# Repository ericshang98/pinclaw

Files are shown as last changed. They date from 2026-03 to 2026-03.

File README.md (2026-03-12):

<div align="center">

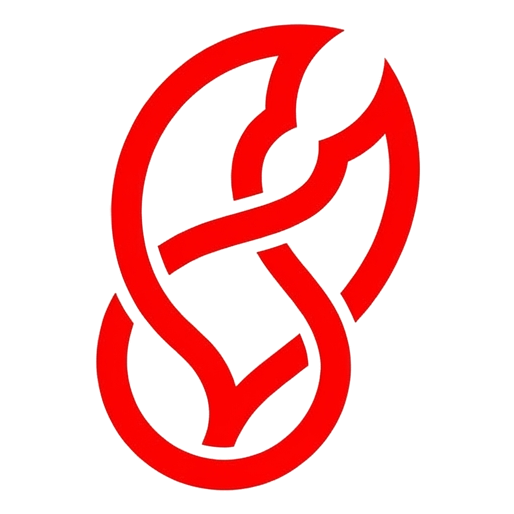
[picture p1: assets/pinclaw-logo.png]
Pinclaw

PinClaw

<a href="https://pinclaw.ai">pinclaw.ai</a>

The first hardware product built for [OpenClaw](https://openclaw.ai). A tiny wearable AI clip — always listening, always acting, powered by your own AI agent.

<p align="center">
  Pinclaw
</p>

&ensp;&ensp;&ensp;
&ensp;&ensp;&ensp;
&ensp;&ensp;&ensp;


<h3>

[Website](https://pinclaw.ai) | [App Store](https://apps.apple.com/app/pinclaw/id6760344343) | [Docs](https://pinclaw.ai/doc) | [Buy Pinclaw](https://pinclaw.ai/#pricing)

</h3>

</div>

## Your Closest Agent. &ensp; OpenClaw + Pinclaw

We believe AI agents should feel effortless — not something you open, but something that's just there. Pinclaw is designed to let agents truly integrate into your life. No screen to unlock, no app to open. Just speak, and your agent hears you, thinks, and acts.

Your own server, your own AI agent, ready to go. Powered by [OpenClaw](https://openclaw.ai).

## 🎙 Why Us

- **5× faster input** — Phone: unlock, open app, type (~30s). Pinclaw: tap, speak, done (~6s). Language is the most natural interface.
- **Your phone, unlocked** — Pinclaw talks directly to your iPhone. Calendar, reminders, contacts — your AI agent uses them without you ever touching the screen.
- **No screen required** — Clip it on and forget it. Ask questions, set reminders, get updates — all hands-free, all voice.

## 🛠 Quick Start

```bash
openclaw plugin add @openclaw/pinclaw
openclaw gateway --force
```

[](https://apps.apple.com/app/pinclaw/id6760344343)

→ [Full setup guide](https://pinclaw.ai/doc?tab=getting-started)

For a complete setup guide, see the [documentation](https://pinclaw.ai/doc).

## ☁️ Works With Every Claw

Pinclaw integrates with the entire OpenClaw ecosystem — cloud or self-hosted, plug in and go.

| Platform | Type | Platform | Type |
|---|---|---|---|
| [**OpenClaw**](https://openclaw.ai) | Self-hosted | **ClawApp** | Managed |
| **KiloClaw** | Managed | **EasyClaw** | Managed |
| **Clawi.ai** | Managed | **HostedClaws** | Managed |
| **chowder.dev** | Managed | **ClawSimple** | Managed |

One plugin. Any platform. Your choice.

## 📲 Device Skills

Other AI hardware lives in a bubble — it can't see your calendar, doesn't know your contacts, and has no idea what you did today. Pinclaw is different.

<p align="center">
  Pinclaw Device Skills
</p>

| Skill | What Your Agent Can Do |
|---|---|
| **Calendar** | View and create events, check availability |
| **Reminders** | Manage tasks and to-do lists |
| **Contacts** | Search your contacts |
| **Timer** | Set and cancel timers |
| **Health** | Read health data summaries |
| **Location** | Get your current location |
| **HomeKit** | Control your smart home devices |

> All data stays on your iPhone. You control every permission.

## 🔀 Two Ways to Use

**Cloud Mode — Zero Setup**
Buy the clip, download the app, subscribe. We run a dedicated OpenClaw instance for you — your own agent, your own database, managed by us.

**My OpenClaw Mode — Full Control**
Run OpenClaw on your own machine. Install the plugin, connect via relay. Your AI, your rules, your hardware.

## 🔩 Core Technologies

| Technology | Description |
|---|---|
| **BLE Audio Streaming** | High-quality audio streams wirelessly over BLE. Custom packet protocol with CRC32 integrity checks. |
| **On-Device Speech Recognition** | Transcribed locally on iPhone using Apple Speech. No audio leaves your device. |
| **AI Agent Services** | Connect to Claude, GPT, and other frontier models through the OpenClaw platform. |

## 📂 In this repo:

- [plugin](plugin) — OpenClaw channel plugin (`@openclaw/pinclaw`), TypeScript
- [firmware](firmware) — Zephyr RTOS firmware for XIAO nRF52840 Sense, C
- [hardware](hardware) — 3D case designs (Fusion 360 / STL), PCB files

## 📖 Documentation:

- [Introduction](https://pinclaw.ai/doc)
- [Getting Started](https://pinclaw.ai/doc?tab=getting-started)
- [Core Protocol](https://pinclaw.ai/doc?tab=core)
- [Plugin Development](https://pinclaw.ai/doc?tab=plugin)
- [API Reference](https://pinclaw.ai/doc?tab=reference)

## 🤝 Contributions

- Check out the [current issues](https://github.com/ericshang98/pinclaw/issues).
- Join the [Discord](https://discord.gg/628R3FbV).
- Fork, branch, and open a Pull Request.

## 📄 Licensing

Pinclaw is available under <a href="https://github.com/ericshang98/pinclaw/blob/main/LICENSE">MIT License</a>

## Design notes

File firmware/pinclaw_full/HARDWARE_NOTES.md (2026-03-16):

# Pinclaw PCB V1.0 Hardware Notes

## Button Pin Mapping (IMPORTANT — pins are swapped vs silkscreen!)

The physical buttons on the PCB are **swapped** relative to the schematic labels:

| Physical Button | Actual GPIO | Firmware Function |
|---|---|---|
| Left button (closer to USB) | D5 | PTT (Push-to-Talk, recording) |
| Right button (further from USB) | D4 | Action (Play / SD sync) |

**The schematic says D4=PTT, D5=Action, but the actual wiring is reversed.**

This means in firmware:
- `PIN_PTT` should be `5` (not `4`)
- `PIN_ACTION` should be `4` (not `5`)

## Known Issues

- Both recording (PDM mic) and playback (I2S speaker) exhibit audible electrical noise / buzzing
- Possible causes: PDM clock interference, shared power rail noise, missing decoupling caps

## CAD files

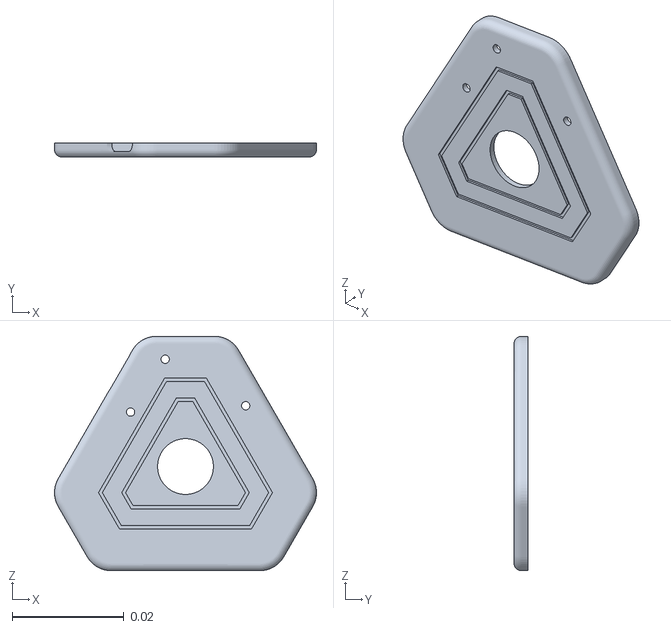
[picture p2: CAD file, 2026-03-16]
hardware/enclosure/stl/speaker_grille.stl
0.0469 x 0.0025 x 0.042

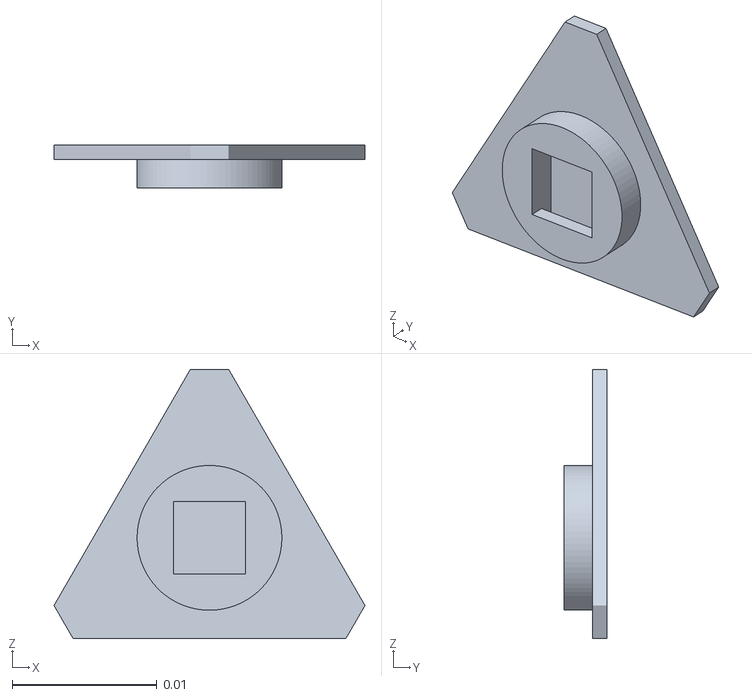
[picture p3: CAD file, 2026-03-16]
hardware/enclosure/stl/button_cap.stl
0.0215 x 0.003 x 0.0186

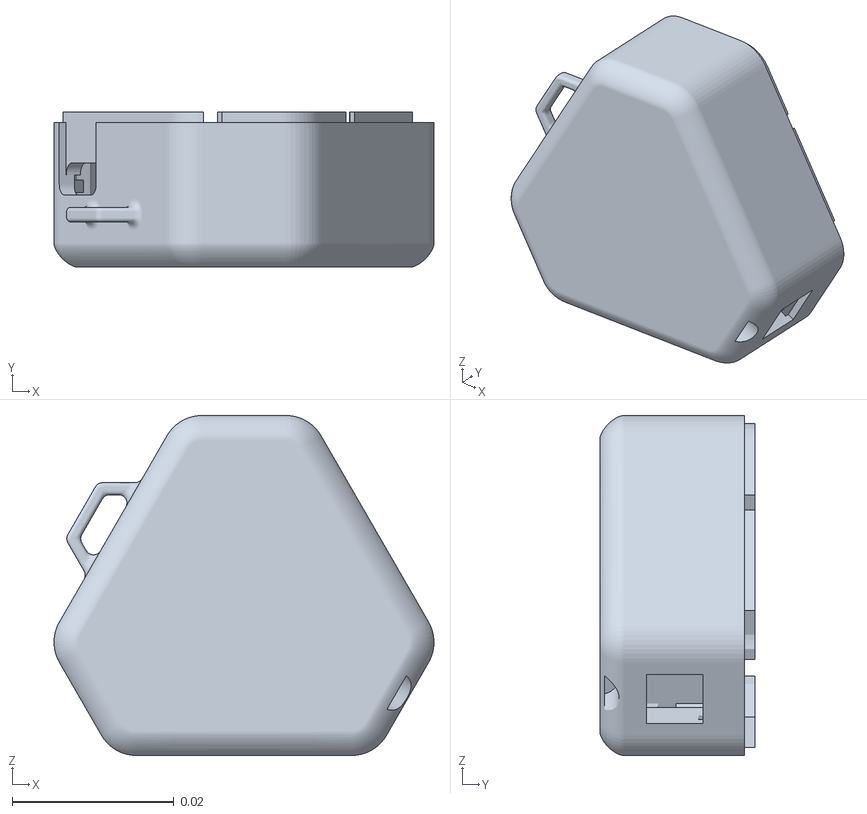
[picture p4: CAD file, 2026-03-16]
hardware/enclosure/stl/base.stl
0.0469 x 0.0192 x 0.042

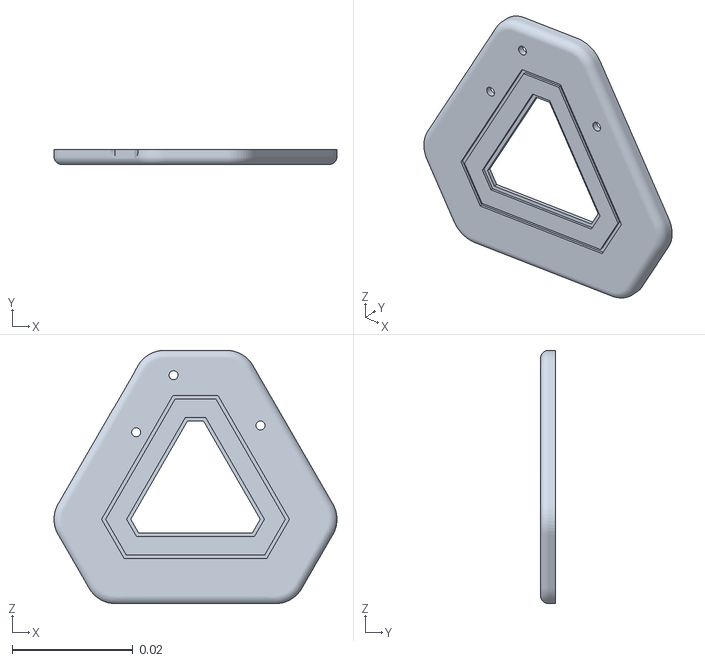
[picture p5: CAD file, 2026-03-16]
hardware/enclosure/stl/top_cover.stl
0.0469 x 0.0025 x 0.042

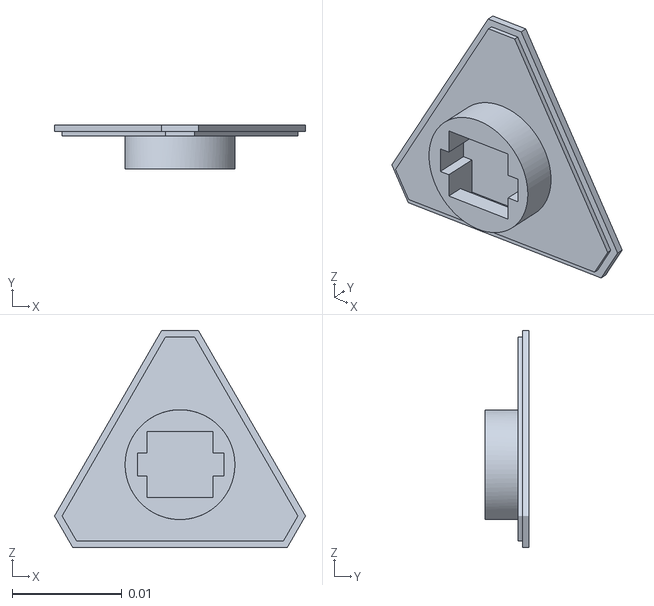
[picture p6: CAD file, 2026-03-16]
hardware/enclosure/stl/button_key.stl
0.0229 x 0.004 x 0.0198

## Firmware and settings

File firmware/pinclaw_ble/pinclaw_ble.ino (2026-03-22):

// Pinclaw BLE Audio Clip — XIAO nRF52840 Sense Firmware
// Records PDM microphone audio, encodes with Opus (CELT mode), streams via BLE in real-time
// iPhone triggers recording via BLE write command (0x01=start, 0x00=stop)

#include <bluefruit.h>
#include <PDM.h>

extern "C" {
  #include "opus.h"
}

// ============================================================
// BLE UUIDs — must match iOS app and Mac simulator
// ============================================================
#define SERVICE_UUID       "12345678-1234-1234-1234-123456789ABC"
#define TEXT_CHAR_UUID     "12345678-1234-1234-1234-123456789ABD"
#define AUDIO_CHAR_UUID    "12345678-1234-1234-1234-123456789ABE"
#define HEARTBEAT_CHAR_UUID "12345678-1234-1234-1234-123456789ABF"

// ============================================================
// BLE packet types
// ============================================================
#define PKT_START     0x01
#define PKT_DATA      0x02
#define PKT_END       0x03
#define PKT_HEARTBEAT 0x04

// ============================================================
// Single-button config
// ============================================================
#define PIN_BUTTON        5   // D5 — single button (active LOW, internal pullup)
#define DEBOUNCE_MS       50
#define LONG_PRESS_MS     500  // hold > 500ms = start recording
#define DOUBLE_TAP_MS     300  // window for second tap
#define CMD_PLAY          0x20 // button tap → phone triggers Interactive AI

// ============================================================
// Audio config
// ============================================================
#define SAMPLE_RATE       16000
#define PDM_BUFFER_SIZE   512    // samples per PDM callback
#define MAX_RECORD_SEC    10
#define SILENCE_THRESHOLD 600   // tuned for 0dB PDM gain (noise peak ~400)
#define SILENCE_TIMEOUT_MS 5000

// BLE MTU and packet sizing
// nRF52840 max MTU = 247, ATT header = 3, so max notify payload = 244
#define BLE_MTU           247
#define DATA_HEADER_SIZE  3     // type(1) + seqNo(2)
#define DATA_PAYLOAD_SIZE (BLE_MTU - DATA_HEADER_SIZE)  // 244

// ============================================================
// Opus encoder config
// ============================================================
#define OPUS_FRAME_SAMPLES 160   // 10ms at 16kHz
#define OPUS_MAX_PACKET    320   // max encoded frame bytes
#define OPUS_ENCODER_SIZE  7180  // opus_encoder_get_size(1)

// Codec ID for BLE START packet (matches OMI/Friend project)
#define CODEC_OPUS 0x14

// ============================================================
// State machine
// ============================================================
enum FirmwareState {
  STATE_INIT,
  STATE_IDLE,
  STATE_RECORDING
};

volatile FirmwareState currentState = STATE_INIT;

// ============================================================
// BLE objects
// ============================================================
BLEService        pinclawService(SERVICE_UUID);
BLECharacteristic textChar(TEXT_CHAR_UUID);
BLECharacteristic audioChar(AUDIO_CHAR_UUID);
BLECharacteristic heartbeatChar(HEARTBEAT_CHAR_UUID);

// ============================================================
// PDM microphone
// ============================================================
short pdmBuffer[PDM_BUFFER_SIZE];
volatile int pdmSamplesRead = 0;

// ============================================================
// Opus encoder state (statically allocated, no malloc)
// ============================================================
static uint8_t opusState[OPUS_ENCODER_SIZE] __attribute__((aligned(4)));
static OpusEncoder* opusEnc = (OpusEncoder*)opusState;

// PCM accumulator for Opus frames (160 samples = 10ms)
int16_t pcmAccum[OPUS_FRAME_SAMPLES];
int pcmAccumPos = 0;
uint16_t opusSeqNo = 0;
uint8_t opusOutBuf[OPUS_MAX_PACKET];

// Silence detection
volatile uint32_t lastSoundTime = 0;
volatile uint32_t recordStartTime = 0;

// Heartbeat
uint16_t heartbeatCounter = 0;
uint32_t lastHeartbeatTime = 0;
#define HEARTBEAT_INTERVAL_MS 50000  // 50 seconds

// Connection state
volatile bool isConnected = false;

// Serial test mode (record via serial command, dump Opus frames to serial)
volatile bool serialTestMode = false;

// ============================================================
// Single-button state
// ============================================================
bool btnPressed = false;
bool lastBtnState = HIGH;
uint32_t lastBtnDebounce = 0;
uint32_t btnPressTime = 0;
uint32_t btnReleaseTime = 0;
uint8_t tapCount = 0;
bool btnRecording = false;  // true while long-press recording is active

// === 2nd-order Butterworth high-pass filter at 80Hz ===
// Removes 50Hz mains hum + DC offset while preserving speech (fundamental ~100Hz+)
// Designed for fs=16000Hz, fc=80Hz
// Pre-computed coefficients (scipy.signal.butter(2, 80/8000, 'high'))
#define HPF2_B0  0.96907f
#define HPF2_B1 -1.93815f
#define HPF2_B2  0.96907f
#define HPF2_A1 -1.93729f
#define HPF2_A2  0.93900f
float hpfX1 = 0, hpfX2 = 0;  // input delay line
float hpfY1 = 0, hpfY2 = 0;  // output delay line

// === Noise gate (two-stage) ===
// Stage 1: Per-sample soft gate — anything below SOFT_GATE is zeroed
// Stage 2: Per-chunk hard gate — if chunk RMS < HARD_GATE, zero the whole chunk
// This ensures silence is truly silent while preserving speech dynamics
#define SOFT_GATE_THRESHOLD  120   // per-sample: below this amplitude -> 0
#define HARD_GATE_THRESHOLD_SQ (400L * 400L)  // per-chunk RMS^2: below this -> all zeros

// Startup discard — skip first N ms of PDM data (transient)
#define STARTUP_DISCARD_MS 80
volatile bool startupDiscardDone = false;


// ============================================================
// Base64 encoder (for serial test mode)
// ============================================================
static const char b64chars[] = "ABCDEFGHIJKLMNOPQRSTUVWXYZabcdefghijklmnopqrstuvwxyz0123456789+/";

void serialBase64(const uint8_t* data, uint32_t len) {
  char line[77];  // 76 chars + null
  int linePos = 0;

  for (uint32_t i = 0; i < len; i += 3) {
    uint32_t n = ((uint32_t)data[i]) << 16;
    if (i + 1 < len) n |= ((uint32_t)data[i + 1]) << 8;
    if (i + 2 < len) n |= data[i + 2];

    line[linePos++] = b64chars[(n >> 18) & 63];
    line[linePos++] = b64chars[(n >> 12) & 63];
    line[linePos++] = (i + 1 < len) ? b64chars[(n >> 6) & 63] : '=';
    line[linePos++] = (i + 2 < len) ? b64chars[n & 63] : '=';

    if (linePos >= 76) {
      line[linePos] = '\0';
      Serial.println(line);
      linePos = 0;
    }
  }
  if (linePos > 0) {
    line[linePos] = '\0';
    Serial.println(line);
  }
}


// ============================================================
// PDM callback — called from interrupt context
// ============================================================
void onPDMdata() {
  int bytesAvailable = PDM.available();
  PDM.read(pdmBuffer, bytesAvailable);
  pdmSamplesRead = bytesAvailable / 2;
}


// ============================================================
// Initialize Opus encoder
// ============================================================
void initOpusEncoder() {
  int err = opus_encoder_init(opusEnc, 16000, 1, OPUS_APPLICATION_RESTRICTED_LOWDELAY);
  if (err != OPUS_OK) {
    Serial.printf("[OPUS] encoder_init failed: %d\n", err);
    return;
  }

  opus_encoder_ctl(opusEnc, OPUS_SET_BITRATE(32000));
  opus_encoder_ctl(opusEnc, OPUS_SET_VBR(1));
  opus_encoder_ctl(opusEnc, OPUS_SET_VBR_CONSTRAINT(0));
  opus_encoder_ctl(opusEnc, OPUS_SET_COMPLEXITY(3));
  opus_encoder_ctl(opusEnc, OPUS_SET_SIGNAL(OPUS_SIGNAL_VOICE));
  opus_encoder_ctl(opusEnc, OPUS_SET_LSB_DEPTH(16));
  opus_encoder_ctl(opusEnc, OPUS_SET_DTX(0));
  opus_encoder_ctl(opusEnc, OPUS_SET_INBAND_FEC(0));
  opus_encoder_ctl(opusEnc, OPUS_SET_PACKET_LOSS_PERC(0));

  Serial.println("[OPUS] Encoder initialized (32kbps VBR, complexity=3, CELT lowdelay)");
}


// ============================================================
// Send one Opus frame via BLE as a DATA packet
// ============================================================
void sendOpusFrame(const uint8_t* frameData, int frameLen) {
  if (!isConnected || !audioChar.notifyEnabled()) return;

  // [0x02][seqNo 2B BE][opus_frame_data...]
  uint8_t pkt[DATA_HEADER_SIZE + OPUS_MAX_PACKET];
  pkt[0] = PKT_DATA;
  pkt[1] = (opusSeqNo >> 8) & 0xFF;
  pkt[2] = opusSeqNo & 0xFF;
  memcpy(&pkt[DATA_HEADER_SIZE], frameData, frameLen);

  sendWithRetry(pkt, DATA_HEADER_SIZE + frameLen);
  opusSeqNo++;
}


// ============================================================
// Encode accumulated PCM and send via BLE (or dump to serial)
// ============================================================
void encodeAndSendFrame() {
  int encodedLen = opus_encode(opusEnc, pcmAccum, OPUS_FRAME_SAMPLES, opusOutBuf, OPUS_MAX_PACKET);

  if (encodedLen < 0) {
    Serial.printf("[OPUS] encode error: %d\n", encodedLen);
    return;
  }

  if (serialTestMode) {
    // Dump Opus frame to serial for test script
    Serial.printf(">>> OPUS_FRAME %d\n", encodedLen);
    serialBase64(opusOutBuf, encodedLen);
  } else {
    sendOpusFrame(opusOutBuf, encodedLen);
  }
}


// ============================================================
// Process PDM samples: filter + encode + stream
// ============================================================
void processPDMSamples() {
  if (pdmSamplesRead == 0 || currentState != STATE_RECORDING) return;

  int count = pdmSamplesRead;
  pdmSamplesRead = 0;

  // Discard startup transient
  if (!startupDiscardDone) {
    if (millis() - recordStartTime < STARTUP_DISCARD_MS) {
      return;
    }
    startupDiscardDone = true;
  }

  int16_t peakAmplitude = 0;

  // --- Pass 1: HPF + per-sample soft gate ---
  int64_t energySum = 0;
  for (int i = 0; i < count; i++) {
    float x = (float)pdmBuffer[i];

    // 2nd-order Butterworth HPF at 80Hz — kills 50Hz hum + DC
    float y = HPF2_B0 * x + HPF2_B1 * hpfX1 + HPF2_B2 * hpfX2
                           - HPF2_A1 * hpfY1 - HPF2_A2 * hpfY2;
    hpfX2 = hpfX1; hpfX1 = x;
    hpfY2 = hpfY1; hpfY1 = y;

    int16_t sample = (int16_t)constrain((int32_t)y, -32768, 32767);

    // Per-sample soft gate: small amplitudes -> zero
    if (abs(sample) < SOFT_GATE_THRESHOLD) {
      sample = 0;
    }

    pdmBuffer[i] = sample;
    energySum += (int32_t)sample * sample;
  }

  // --- Per-chunk hard gate: if overall energy is low, zero everything ---
  int64_t avgEnergySq = energySum / count;
  bool gated = (avgEnergySq < HARD_GATE_THRESHOLD_SQ);

  // --- Pass 2: Accumulate into Opus frames and encode ---
  for (int i = 0; i < count; i++) {
    int16_t sample = gated ? 0 : pdmBuffer[i];

    int16_t absSample = abs(sample);
    if (absSample > peakAmplitude) peakAmplitude = absSample;

    // Feed into PCM accumulator
    pcmAccum[pcmAccumPos++] = sample;

    // When we have a full Opus frame (160 samples = 10ms), encode and send
    if (pcmAccumPos >= OPUS_FRAME_SAMPLES) {
      encodeAndSendFrame();
      pcmAccumPos = 0;
    }
  }

  // Update silence detection
  if (peakAmplitude > SILENCE_THRESHOLD) {
    lastSoundTime = millis();
  }

  uint32_t now = millis();

  // Auto-stop on silence (5 seconds)
  if (now - lastSoundTime > SILENCE_TIMEOUT_MS) {
    Serial.println("[REC] Auto-stop: silence detected");
    stopRecording();
    return;
  }

  // In serial test mode, use fixed 5-second duration
  if (serialTestMode && (now - recordStartTime > 5000UL)) {
    Serial.println("[TEST] 5s test recording complete");
    stopRecording();
    return;
  }

  // Hard stop at max duration
  if (now - recordStartTime > (MAX_RECORD_SEC * 1000UL)) {
    Serial.println("[REC] Auto-stop: max duration reached");
    stopRecording();
    return;
  }
}


// ============================================================
// Recording control
// ============================================================
void startRecording() {
  if (currentState != STATE_IDLE) return;

  Serial.println("[REC] Starting recording...");

  // Reset Opus encoder state
  opus_encoder_ctl(opusEnc, OPUS_RESET_STATE);

  // Reset PCM accumulator and sequence number
  pcmAccumPos = 0;
  opusSeqNo = 0;

  // Reset filter state
  hpfX1 = hpfX2 = hpfY1 = hpfY2 = 0;
  startupDiscardDone = false;

  // Reset silence detection
  lastSoundTime = millis();
  recordStartTime = millis();

  // Send START packet immediately: [0x01][codec=0x14][0x00][0x00][0x00][0x00]
  if (!serialTestMode) {
    uint8_t startPkt[6];
    startPkt[0] = PKT_START;
    startPkt[1] = CODEC_OPUS;  // codec: Opus (0x14 = 20)
    startPkt[2] = 0x00;
    startPkt[3] = 0x00;
    startPkt[4] = 0x00;
    startPkt[5] = 0x00;
    sendWithRetry(startPkt, 6);
    Serial.println("[BLE] START packet sent (codec=Opus)");
  } else {
    Serial.println(">>> OPUS_START");
  }

  // Start PDM mic
  if (!PDM.begin(1, SAMPLE_RATE)) {
    Serial.println("[REC] PDM start failed!");
    return;
  }

  // PDM gain: +12dB (0x40), matches OMI/Friend config
  // 0x28=0dB, each +1 = +0.5dB
  NRF_PDM->GAINL = 0x40;
  NRF_PDM->GAINR = 0x40;

  Serial.println("[REC] PDM started (gain=+12dB)");

  // Set LED blue for recording
  setLED(0, 0, 1);  // blue

  currentState = STATE_RECORDING;
}

void stopRecording() {
  if (currentState != STATE_RECORDING) return;

  // Stop PDM mic
  PDM.end();
  Serial.println("[REC] PDM stopped");

  // Flush remaining PCM accumulator (pad with zeros if < 160 samples)
  if (pcmAccumPos > 0) {
    // Zero-pad the remainder
    for (int i = pcmAccumPos; i < OPUS_FRAME_SAMPLES; i++) {
      pcmAccum[i] = 0;
    }
    encodeAndSendFrame();
    pcmAccumPos = 0;
  }

  uint32_t duration = millis() - recordStartTime;
  Serial.printf("[REC] Stopped. Duration: %lu ms, Opus frames: %u\n", duration, opusSeqNo);

  // Send END packet: [0x03][totalFrames 4B BE]
  if (!serialTestMode) {
    uint8_t endPkt[5];
    endPkt[0] = PKT_END;
    endPkt[1] = (opusSeqNo >> 24) & 0xFF;
    endPkt[2] = (opusSeqNo >> 16) & 0xFF;
    endPkt[3] = (opusSeqNo >> 8) & 0xFF;
    endPkt[4] = opusSeqNo & 0xFF;
    sendWithRetry(endPkt, 5);
    Serial.printf("[BLE] END packet sent (frames=%u)\n", opusSeqNo);
  } else {
    Serial.printf(">>> OPUS_END %u\n", opusSeqNo);
  }

  // Set LED off
  setLED(0, 0, 0);

  if (serialTestMode) {
    serialTestMode = false;
  }

  currentState = isConnected ? STATE_IDLE : STATE_INIT;
  if (isConnected) setLED(0, 1, 0);      // green = connected idle
  else setLED(1, 0, 0);                    // red = disconnected
}


// ============================================================
// BLE packet sender with flow control
// ============================================================
void sendWithRetry(const uint8_t* data, uint16_t len) {
  uint32_t start = millis();
  while (!audioChar.notify(data, len)) {
    if (millis() - start > 500) {
      Serial.println("[BLE] Send timeout, dropping packet");
      return;
    }
    delay(1);  // yield to BLE stack
  }
}


// ============================================================
// LED control (XIAO nRF52840 — active LOW)
// ============================================================
void setLED(bool red, bool green, bool blue) {
  digitalWrite(LED_RED,   red   ? LOW : HIGH);
  digitalWrite(LED_GREEN, green ? LOW : HIGH);
  digitalWrite(LED_BLUE,  blue  ? LOW : HIGH);
}


// ============================================================
// BLE callbacks
// ============================================================
void onConnect(uint16_t conn_handle) {
  isConnected = true;
  currentState = STATE_IDLE;
  setLED(0, 1, 0);  // green = connected

  BLEConnection* conn = Bluefruit.Connection(conn_handle);
  char name[32] = {0};
  conn->getPeerName(name, sizeof(name));
  Serial.printf("[BLE] Connected: %s\n", name);
}

void onDisconnect(uint16_t conn_handle, uint8_t reason) {
  isConnected = false;

  // Stop recording if in progress
  if (currentState == STATE_RECORDING) {
    PDM.end();
    pcmAccumPos = 0;
  }

  currentState = STATE_INIT;
  setLED(1, 0, 0);  // red = disconnected

  Serial.printf("[BLE] Disconnected, reason=0x%02X\n", reason);
}

// Text characteristic write handler — iPhone sends recording commands
void onTextWrite(uint16_t conn_hdl, BLECharacteristic* chr, uint8_t* data, uint16_t len) {
  if (len < 1) return;

  uint8_t command = data[0];
  Serial.printf("[CMD] Received command: 0x%02X\n", command);

  switch (command) {
    case 0x01:  // Start recording
      startRecording();
      break;
    case 0x00:  // Stop recording
      if (currentState == STATE_RECORDING) {
        stopRecording();
      }
      break;
    default:
      Serial.printf("[CMD] Unknown command: 0x%02X\n", command);
      break;
  }
}


// ============================================================
// Heartbeat
// ============================================================
void sendHeartbeat() {
  if (!isConnected || !heartbeatChar.notifyEnabled()) return;

  // [0x04][counter:2B BE][flags:1B]
  uint8_t pkt[4];
  pkt[0] = PKT_HEARTBEAT;
  pkt[1] = (heartbeatCounter >> 8) & 0xFF;
  pkt[2] = heartbeatCounter & 0xFF;
  pkt[3] = (currentState == STATE_RECORDING) ? 0x01 : 0x00;

  if (heartbeatChar.notify(pkt, 4)) {
    Serial.printf("[HB] #%u sent (flags=0x%02X)\n", heartbeatCounter, pkt[3]);
  }
  heartbeatCounter++;
}


// ============================================================
// Single-button handling
//
// Gestures:
//   Long press (>500ms hold) → record audio (release to stop)
//   Single tap (<500ms)      → PLAY command (Interactive AI)
//   Double tap               → toggle BLE advertising
// ============================================================
void onSingleTap() {
  if (isConnected && textChar.notifyEnabled()) {
    uint8_t cmd = CMD_PLAY;
    textChar.notify(&cmd, 1);
    Serial.println("[BTN] Single tap -> PLAY");
  } else {
    Serial.println("[BTN] Single tap (no BLE)");
  }
}

void onDoubleTap() {
  if (Bluefruit.Advertising.isRunning()) {
    Bluefruit.Advertising.stop();
    Serial.println("[BTN] Double tap -> BLE advertising OFF");
    setLED(1, 1, 0);  // yellow = advertising off
  } else {
    Bluefruit.Advertising.start(0);
    Serial.println("[BTN] Double tap -> BLE advertising ON");
    setLED(0, 0, 1);  // blue = advertising
  }
}

void handleButton() {
  uint32_t now = millis();

  // --- Debounce ---
  bool reading = digitalRead(PIN_BUTTON);
  if (reading != lastBtnState) {
    lastBtnDebounce = now;
  }
  lastBtnState = reading;
  if ((now - lastBtnDebounce) < DEBOUNCE_MS) return;

  bool newPressed = (reading == LOW);

  if (newPressed != btnPressed) {
    btnPressed = newPressed;

    if (btnPressed) {
      // --- Button pressed ---
      btnPressTime = now;
      if (tapCount == 1 && (now - btnReleaseTime) < DOUBLE_TAP_MS) {
        tapCount = 2;  // second press within double-tap window
      } else {
        tapCount = 1;
      }

    } else {
      // --- Button released ---
      btnReleaseTime = now;

      if (btnRecording) {
        // Was recording via long press — stop
        btnRecording = false;
        if (currentState == STATE_RECORDING) {
          stopRecording();
        }
        tapCount = 0;
        return;
      }

      if (tapCount == 2) {
        // Double tap completed on release
        onDoubleTap();
        tapCount = 0;
        return;
      }
      // tapCount == 1, short release — wait for possible double tap
    }
  }

  // --- Long press detection (while still holding) ---
  if (btnPressed && !btnRecording && tapCount == 1) {
    if ((now - btnPressTime) >= LONG_PRESS_MS) {
      btnRecording = true;
      tapCount = 0;
      if (currentState == STATE_IDLE) {
        startRecording();
      }
    }
  }

  // --- Single tap timeout (released, waiting for possible double tap) ---
  if (!btnPressed && tapCount == 1 && !btnRecording) {
    if ((now - btnReleaseTime) >= DOUBLE_TAP_MS) {
      onSingleTap();
      tapCount = 0;
    }
  }
}
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
void loop() {
  // Process PDM samples (filter + encode + stream)
  if (currentState == STATE_RECORDING) {
    processPDMSamples();
  }

  // Handle single button
  handleButton();

  // Heartbeat timer
  if (isConnected && (millis() - lastHeartbeatTime >= HEARTBEAT_INTERVAL_MS)) {
    sendHeartbeat();
    lastHeartbeatTime = millis();
  }

  // Update state on first connection
  if (isConnected && currentState == STATE_INIT) {
    currentState = STATE_IDLE;
  }

  // Standalone idle: allow button recording even without BLE
  if (!isConnected && currentState == STATE_INIT) {
    currentState = STATE_IDLE;
    setLED(1, 0, 0);  // red = standalone mode
  }

  // Serial test command: send 'T' to trigger test recording
  if (Serial.available()) {
    char cmd = Serial.read();
    if (cmd == 'T' && currentState != STATE_RECORDING) {
      Serial.println("[TEST] Serial test mode activated");
      serialTestMode = true;
      currentState = STATE_IDLE;  // allow recording even without BLE
      startRecording();
    }
  }

  // Small delay to prevent busy-waiting
  delay(1);
}

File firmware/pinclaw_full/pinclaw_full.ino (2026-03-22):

// Pinclaw Full Firmware — XIAO nRF52840 Sense (PCB V1.0)
// BLE Audio (Opus) + Buttons + I2S Speaker + SD Card + Motor + WS2812B LED
//
// Pin Map (PCB V1.0 — pinc sch2):
//   D0  = SD Card CS
//   D1  = I2S DIN  (MAX98357A audio data)
//   D2  = I2S LRCLK (MAX98357A word select)
//   D3  = I2S BCLK  (MAX98357A bit clock)
//   D5  = Single Button (active LOW, internal pullup)
//   D6  = WS2812B LED DIN
//   D7  = Vibration Motor (via 2N7002 MOSFET, HIGH=ON)
//   D8  = SD Card SCK  (SPI)
//   D9  = SD Card MISO (SPI)
//   D10 = SD Card MOSI (SPI)

#include <bluefruit.h>
#include <PDM.h>
#include <SPI.h>
#include <SdFat.h>
#include <Adafruit_NeoPixel.h>
#include <nrf.h>

extern "C" {
  #include "opus.h"
}

// ============================================================
// Pin Definitions (PCB V1.0)
// ============================================================
#define PIN_SD_CS       0   // D0 — SD card chip select
#define PIN_I2S_DIN     1   // D1 — I2S data to MAX98357A
#define PIN_I2S_LRCLK   2   // D2 — I2S word select
#define PIN_I2S_BCLK    3   // D3 — I2S bit clock
#define PIN_BUTTON      5   // D5 — Single button (active LOW, internal pullup)
#define PIN_LED_DIN     6   // D6 — WS2812B RGB LED
#define PIN_MOTOR       7   // D7 — Vibration motor

// GPIO numbers for I2S register config (from variant.cpp)
#define GPIO_I2S_DIN    3   // P0.03 (D1)
#define GPIO_I2S_LRCLK  28  // P0.28 (D2)
#define GPIO_I2S_BCLK   29  // P0.29 (D3)

// ============================================================
// BLE UUIDs — must match iOS app
// ============================================================
#define SERVICE_UUID        "12345678-1234-1234-1234-123456789ABC"
#define TEXT_CHAR_UUID      "12345678-1234-1234-1234-123456789ABD"
#define AUDIO_CHAR_UUID     "12345678-1234-1234-1234-123456789ABE"
#define HEARTBEAT_CHAR_UUID "12345678-1234-1234-1234-123456789ABF"
#define SPEAKER_CHAR_UUID   "12345678-1234-1234-1234-123456789AC0"

// ============================================================
// BLE packet types
// ============================================================
#define PKT_START     0x01
#define PKT_DATA      0x02
#define PKT_END       0x03
#define PKT_HEARTBEAT 0x04
#define CMD_PLAY      0x20  // Action button → phone triggers Interactive AI
#define CMD_SHUTDOWN  0x40  // App commands device to shut down

// Speaker (reverse audio) packet types
#define SPK_START     0x30
#define SPK_DATA      0x31
#define SPK_END       0x32
#define SPK_STOP      0x33

// ============================================================
// Audio config
// ============================================================
#define SAMPLE_RATE        16000
#define PDM_BUFFER_SIZE    512
#define MAX_RECORD_SEC     10
#define SILENCE_THRESHOLD  600   // tuned for +12dB PDM gain
#define SILENCE_TIMEOUT_MS 5000

// BLE MTU
#define BLE_MTU            247
#define DATA_HEADER_SIZE   3
#define DATA_PAYLOAD_SIZE  (BLE_MTU - DATA_HEADER_SIZE)

// ============================================================
// Opus encoder config
// ============================================================
#define OPUS_FRAME_SAMPLES 160   // 10ms at 16kHz
#define OPUS_MAX_PACKET    320   // max encoded frame bytes
#define OPUS_ENCODER_SIZE  7180  // opus_encoder_get_size(1)
#define CODEC_OPUS         0x14  // codec ID for BLE START packet

// Opus offline buffer (for SD card saving when BLE not connected)
#define OPUS_OFFLINE_BUF_SIZE  80000  // restored — testing if memory layout was the issue
#define OPUS_MAX_FRAMES        600    // 10s * 100 fps = 1000 max, 600 is comfortable

// ============================================================
// Single-button config
// ============================================================
#define DEBOUNCE_MS        50
#define LONG_PRESS_MS      500   // hold > 500ms = start recording
#define DOUBLE_TAP_MS      300   // window for second tap

// ============================================================
// I2S tone config
// ============================================================
// MCK = 32MHz / 32 = 1MHz, RATIO = 32X → LRCLK = 31250 Hz
#define I2S_SAMPLE_RATE    31250
#define I2S_BUF_SAMPLES    1024   // samples per DMA buffer
// DMA buffer: stereo 32-bit words (left + right packed as int32)
static int32_t i2sTxBuf[I2S_BUF_SAMPLES] __attribute__((aligned(4)));

// ============================================================
// State machine
// ============================================================
enum FirmwareState {
  STATE_INIT,
  STATE_IDLE,
  STATE_RECORDING,
  STATE_SD_SYNC,
  STATE_PLAYING_SPK
};

volatile FirmwareState currentState = STATE_INIT;

// ============================================================
// BLE objects
// ============================================================
BLEService        pinclawService(SERVICE_UUID);
BLECharacteristic textChar(TEXT_CHAR_UUID);
BLECharacteristic audioChar(AUDIO_CHAR_UUID);
BLECharacteristic heartbeatChar(HEARTBEAT_CHAR_UUID);
BLECharacteristic speakerChar(SPEAKER_CHAR_UUID);

// ============================================================
// Speaker playback (reverse audio: phone → hardware)
// ============================================================
#define SPK_RING_SIZE    8192   // 8KB ring buffer (~1s of ADPCM @ 16kHz)
#define SPK_DMA_SAMPLES  256    // samples per DMA half-buffer

uint8_t spkRingBuf[SPK_RING_SIZE];
volatile uint32_t spkRingHead = 0;  // BLE write position
volatile uint32_t spkRingTail = 0;  // I2S consume position

static int32_t spkDmaBufA[SPK_DMA_SAMPLES] __attribute__((aligned(4)));
static int32_t spkDmaBufB[SPK_DMA_SAMPLES] __attribute__((aligned(4)));
volatile bool spkUsingBufA = true;
volatile bool spkStreamEnded = false;  // set when SPK_END received
volatile bool spkPlaying = false;

// Speaker ADPCM decoder state (separate from recorder encoder)
int16_t spkAdpcmPrev = 0;
int8_t  spkAdpcmIndex = 0;

// ============================================================
// WS2812B LED
// ============================================================
Adafruit_NeoPixel pixel(1, PIN_LED_DIN, NEO_GRB + NEO_KHZ800);

// ============================================================
// PDM microphone
// ============================================================
short pdmBuffer[PDM_BUFFER_SIZE];
volatile int pdmSamplesRead = 0;

// ============================================================
// Opus encoder state (statically allocated, no malloc)
// ============================================================
static uint8_t opusState[OPUS_ENCODER_SIZE] __attribute__((aligned(4)));
static OpusEncoder* opusEnc = (OpusEncoder*)opusState;

// PCM accumulator for Opus frames (160 samples = 10ms)
int16_t pcmAccum[OPUS_FRAME_SAMPLES];
int pcmAccumPos = 0;
uint16_t opusSeqNo = 0;
uint8_t opusOutBuf[OPUS_MAX_PACKET];
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

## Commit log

2026-03-10 Squashed 'hardware/' content from commit 6cb4714
    git-subtree-dir: hardware
    git-subtree-split: 6cb4714e13e9d06cc6027ea1918e8c3e43ad166e
    [pinclaw_clip_v1.scad, pinclaw_clip_v2.scad, pinclaw_clip_v3.scad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]
2026-03-10 rewrite README based on website content: 15x speed, ecosystem, device skills
2026-03-10 add logo, red Claw text, single product photo
2026-03-10 logo + PinClaw title side by side with red Claw SVG
2026-03-16 feat: add pinclaw_full firmware and noise_test sketch
    - pinclaw_full: complete firmware with BLE audio, buttons, I2S speaker, SD card, motor, WS2812B LED
    - noise_test: hardware debugging sketch for PDM mic noise analysis
    [noise_test.ino, pinclaw_full.ino]
2026-03-16 feat: replace outdated OpenSCAD enclosure with latest Fusion 360 STLs
    - base.stl: bottom shell
    - top_cover.stl: top cover with triangle ventilation holes
    - speaker_grille.stl: speaker grille plate
    - button_cap.stl: button cap
    - button_key.stl: small push button
    Old v1-v4 OpenSCAD files removed — enclosure is now designed in Fusion 360.
    [base.stl, button_cap.stl, button_key.stl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]
